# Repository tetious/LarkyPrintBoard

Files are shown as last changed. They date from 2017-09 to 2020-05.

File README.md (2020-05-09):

# LarkyPrintBoard
This is the PCB for the Lark printer board!

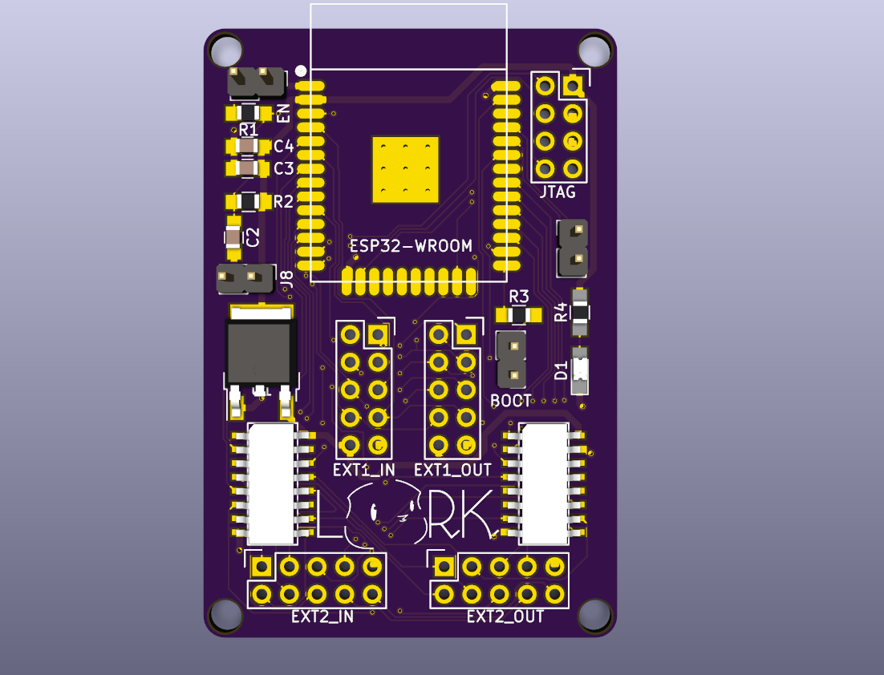
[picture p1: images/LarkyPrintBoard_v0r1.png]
pcb image


The Lark sits between your printer and it's RAMPSish LCD/SD card board and provides a fast and easy to use web 
interface for printing from SD cards. 

It "just works" with most printers/firmwares that support the "LCD Smart Display" style 2-line text LCD.

With minor tweaks, it should work with any printer that supports Marlin.

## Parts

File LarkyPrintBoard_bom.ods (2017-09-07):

Component | Part | References | Value | Quantity Per PCB | Datasheet | Price
1 | C_Small | C3 | 100uF | 1 |  | $0.62 | $0.62
2 | C_Small | C2 | 1nf | 1 |  | $0.01 | $0.01
3 | C_Small | C4 | 1uf | 1 |  | $0.01 | $0.01
4 | Conn_01x02 | J8 | 3V3 | 1 |  | $0.02 | $0.02 | S1011EC-40-ND (https://www.digikey.com/product-detail/en/sullins-connector-solutions/PRPC040SAAN-RC/S1011EC-40-ND/2775214)
5 | Conn_01x02 | J7 | BOOT | 1 |  | $0.02 | $0.02
6 | Conn_01x02 | J6 | EN | 1 |  | $0.02 | $0.02
7 | Conn_02x05_Odd_Even | J1 | EXT1_IN | 1 |  | $0.02 | $0.02 | S2011EC-40-ND (https://www.digikey.com/product-detail/en/sullins-connector-solutions/PRPC040DAAN-RC/S2011EC-40-ND/2775254)
8 | Conn_02x05_Odd_Even | J3 | EXT1_OUT | 1 |  | $0.02 | $0.02
9 | Conn_02x05_Odd_Even | J2 | EXT2_IN | 1 |  | $0.02 | $0.02
10 | Conn_02x05_Odd_Even | J4 | EXT2_OUT | 1 |  | $0.02 | $0.02
11 | Conn_02x04_Odd_Even | J9 | JTAG | 1 |  | $0.02 | $0.02
12 | Conn_01x02 | J5 | UART | 1 |  | $0.02 | $0.02
13 | R_Small | R2 | 12K | 1 |  | $0.01 | $0.01
14 | R_Small | R1 R3 | 470 | 2 |  | $0.01 | $0.02
15 | CBT3257A | U3 U4 | CBT3257A | 2 |  | $0.27 | $0.54
16 | ESP32-WROOM | U2 | ESP32-WROOM | 1 |  | $5.00 | $5.00
17 | LM1117-3.3 | U1 | LM1117-3.3 | 1 | http://www.ti.com/lit/ds/symlink/lm1117.pdf | $0.80 | $0.80
 |  |  |  |  |  |  | $0.00
 |  |  |  |  |  |  | $0.00
 |  |  |  |  |  |  | $0.00
 |  |  |  |  |  |  | $0.00
 |  |  |  |  |  |  | $0.00
Component Groups: | 17 |  |  | 2 | 2x5 IDC cables | $0.83 | $1.66 | H3CCH-1006G-ND (https://www.digikey.com/product-detail/en/assmann-wsw-components/H3CCH-1006G/H3CCH-1006G-ND/1218555)
Component Count: | 19 |  |  |  |  |  | $0.00
Fitted Components: | 19 |  |  |  |  |  | $0.00
Number of PCBs: | 1 |  |  |  |  |  | $0.00
Total components: | 19 |  |  |  |  |  | $0.00
Schematic Version: |  |  |  |  |  |  | $0.00
Schematic Date: |  |  |  |  |  |  | $0.00
BoM Date: | Wed 06 Sep 2017 06:59:28 PM EDT |  |  |  |  |  | $0.00
Schematic Source: | /home/greg/Boards/LarkyPrintBoard/LarkyPrintBoard.sch |  |  |  |  | $7.74 | 8.85
KiCad Version: | Eeschema 4.0.7-e2-6376~58~ubuntu16.04.1

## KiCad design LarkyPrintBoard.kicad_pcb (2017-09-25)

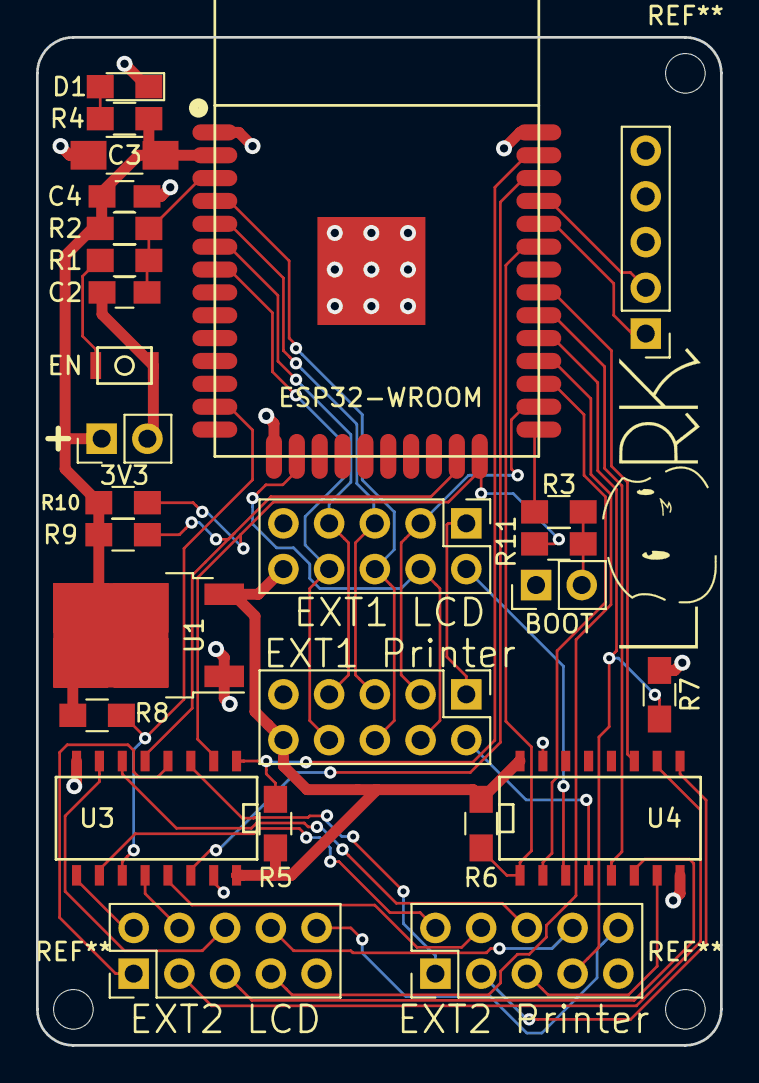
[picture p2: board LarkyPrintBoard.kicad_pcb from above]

Board: 2 copper layers, 38.0 x 56.0 mm, 27 parts (0 on the bottom side), 44 nets.

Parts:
C2: 1nf; C_0805_HandSoldering
C3: 100uF; C_1206_HandSoldering
C4: 1uf; C_0805_HandSoldering
D1: LED; LED_0805_HandSoldering
J1: EXT1 Printer; Pin_Header_Straight_2x05_Pitch2.54mm
J2: EXT2 LCD; Pin_Header_Straight_2x05_Pitch2.54mm
J3: EXT1 LCD; Pin_Header_Straight_2x05_Pitch2.54mm
J4: EXT2 Printer; Pin_Header_Straight_2x05_Pitch2.54mm
J5: UART; Pin_Header_Straight_1x05_Pitch2.54mm
J6: EN; KXT131LHS
J7: BOOT; Pin_Header_Straight_1x02_Pitch2.54mm
J8: 3V3; Pin_Header_Straight_1x02_Pitch2.54mm
R1, R3, R4, R11: 680; R_0805_HandSoldering
R2, R5, R6, R7, R8, R9, R10: 10K; R_0805_HandSoldering
U1: LM1117-3.3; TO-252-2
U2: ESP32-WROOM
U3, U4: CBT3257A; SO-16-N

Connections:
+3V3: C3.2, C4.2, J8.1, R2.1, R4.2, R8.1, R9.1, R10.1, U1.2, U2.2
+5V: J1.10, J3.10, R5.2, R6.2, U1.3, U3.16, U4.16
/BEEP: J1.1, J3.1
/BOOT: R3.1, U2.25
/EN: C2.1, R1.1, R2.2, U2.3
/ENC_1_I: J2.5, U4.6
/ENC_1_O: J4.5, U4.7
/ENC_2_I: J2.3, U4.10
/ENC_2_O: J4.3, U4.9
/ENC_BTN_I: J1.2, U4.4
/ENC_BTN_O: J3.2, U4.3
/ENC_MUX_S: R6.1, U2.33, U4.1
/ESP_ENC_1: U2.30, U4.5
/ESP_ENC_2: U2.31, U4.11
/ESP_ENC_BTN: U2.27, U4.2
/ESP_RX: J5.1, U2.34
/ESP_SD_SS: U2.36, U3.14
/ESP_SPI_MISO: R10.2, R11.1, U2.24, U3.2
/ESP_SPI_MOSI: R9.2, U2.23, U3.5
/ESP_SPI_SCK: R8.2, U2.13, U3.11
/ESP_TX: J5.2, U2.35
/KILL: J2.10, J4.10
/LCD4: J1.5, J3.5, U2.5
/LCD5: J1.6, J3.6, U2.4
/LCD6: J1.7, J3.7, U2.6
/LCD7: J1.8, J3.8, U2.7
/LCD_EN: J1.3, J3.3, U2.26
/LCD_RS: J1.4, J3.4, U2.16
/RESET: J2.8, J4.8
/SD_DETECT_I: J2.7, U2.28
/SD_DETECT_O: J4.7, R7.2, U2.29
/SD_MISO_I: J2.1, U3.4
/SD_MISO_O: J4.1, U3.3
/SD_MOSI_I: J2.6, U3.7
/SD_MOSI_O: J4.6, U3.6
/SD_MUX_S: R5.1, U2.37, U3.1
/SD_SCK_I: J2.2, U3.9
/SD_SCK_O: J4.2, U3.10
/SD_SS_I: J2.4, U3.12
/SD_SS_O: J4.4, U3.13
GND: C2.2, C3.1, C4.1, D1.1, J1.9, J2.9, J3.9, J4.9, J5.5, J6.2, J7.1, J8.2, R7.1, U1.1, U2.1, U2.15, U2.38, U2.39, U3.8, U3.15, U4.8, U4.15
unnamed: D1.2, R4.1
unnamed: J6.1, R1.2
unnamed: J7.2, R3.2, R11.2

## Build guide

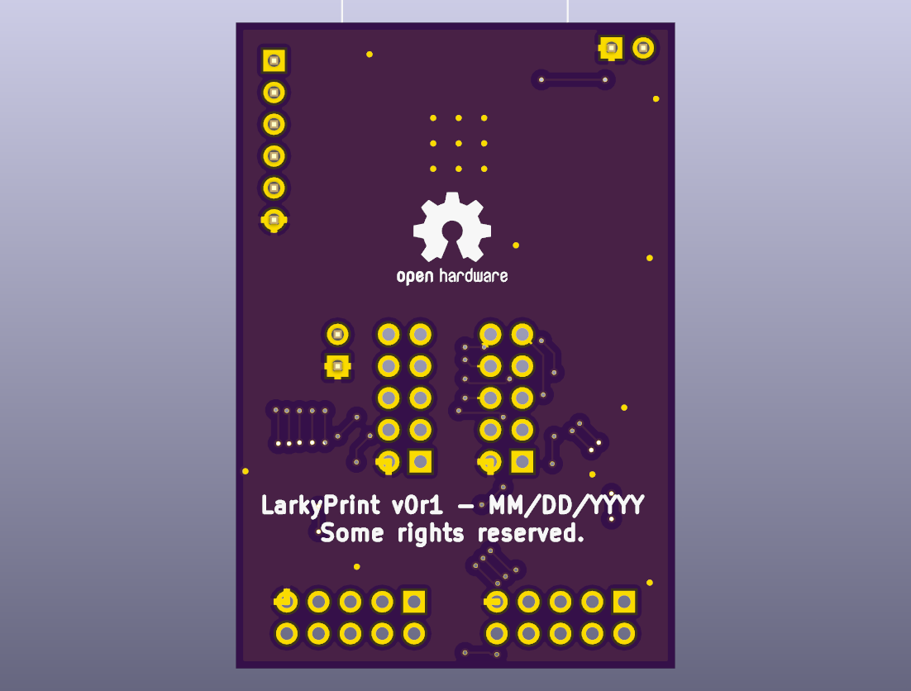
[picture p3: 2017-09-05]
images/LarkyPrintBoard_v0r1_back.png

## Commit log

2017-09-05 Initial checkin.
    [LarkyPrintBoard.kicad_pcb, LarkyPrintBoard.sch]
2017-09-07 Fix output pins on input only ESP32 pins. Add JTAG. Tweaks and improvements.
    [LarkyPrintBoard.kicad_pcb, LarkyPrintBoard.sch, LarkyPrintBoard_bom.ods]
2017-09-07 Alpha 1 final.
    [LarkyPrintBoard.kicad_pcb, LarkyPrintBoard.sch, larkyprint.ods]
2017-09-07 Minor tweaks to document settings.
    [LarkyPrintBoard.sch]
2017-09-24 Tons of changes and fixes. R1A2
    [LarkyPrintBoard.kicad_pcb, LarkyPrintBoard.sch]
2017-09-25 Minor tweaks.
    [LarkyPrintBoard.kicad_pcb, LarkyPrintBoard.sch]
2020-05-09 Update something. ;)
    [larkyprint.ods]

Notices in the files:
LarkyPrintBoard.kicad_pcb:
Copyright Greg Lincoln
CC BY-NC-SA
